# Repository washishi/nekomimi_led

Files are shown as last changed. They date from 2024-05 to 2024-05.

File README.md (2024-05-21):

# Nekomimi LED  
M5StackのGO BOTTOM等に直接取り付けれるオリジナルのネコミミ型LED基板です  
NeoPixel(WS2812)互換のRGB LEDが左右に9個ずつ合計18個付いており独立して色や明るさ等を制御することができます  
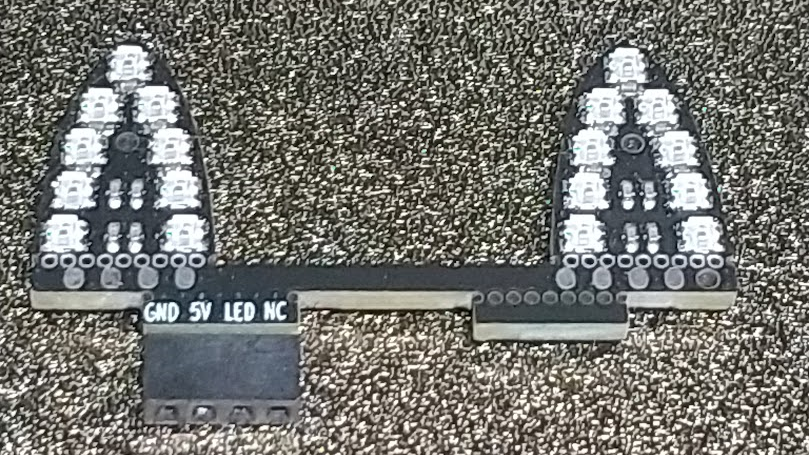
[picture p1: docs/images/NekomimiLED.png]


※完成品 や 組立キット、オプション外装等を[Booth](https://washishi.booth.pm/)で頒布もしています
# 回路図、作り方
  回路図、作り方等の詳細については[こちら](schematics/docs/README.md)へ  
  オプション外装の利用方法については[こちら](case/README.md)へ
  <br>

# 使い方
主に下記に直接取り付けることができます  
- <a href="https://docs.m5stack.com/ja/base/m5go_bottom" target="_blank" rel="noopener noreferrer">M5GO BOTTOM</a> BASIC用 (M5GO,FIREは標準添付)   
- <a href="https://docs.m5stack.com/ja/base/m5go_bottom2" target="_blank" rel="noopener noreferrer">M5GO BOTTOM2</a> CORE2用 (CORE2 for AWS は標準添付)
- <a href="https://docs.m5stack.com/ja/module/M5GO3%20Bottom" target="_blank" rel="noopener noreferrer">M5GO3 BOTTOM</a> CoreS3用 (DINベースにそのままつけた場合はコネクタ位置が異なるため左寄りになります)
  
取り付け例  
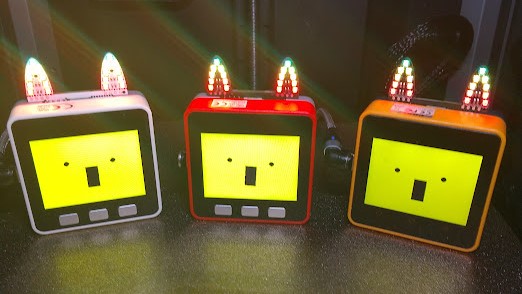
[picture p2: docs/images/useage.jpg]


なおM5Stick系やM5Atom系、M5DialやM5NanoC6などもGROVEポートがあれば基本的に利用可能です  
物理的に干渉する場合はGROVEケーブルとGROVEコネクタを使えば[延長して取り付ける](docs/images/cable_connect.png)こともできます   
<br>  

また[オプション外装](case)を利用してはんだ付けを含む工作を行う場合は下記に取り付け可能となります
  - 直接取り付けできる前記のGO BOTTOM系全て
  - <a href="https://docs.m5stack.com/ja/base/DIN%20BASE" target="_blank" rel="noopener noreferrer">DIN BASE</a> (CoreS3に標準添付)  
  - ししかわさん版(アールティVer. α版,β版)ｽﾀｯｸﾁｬﾝ (V0.2.1基板にPH-4Pコネクタ実装済の物)  

<br>
オプション外装を利用した取り付け例  

&emsp;左から DIN BASE基板ｽﾀｯｸﾁｬﾝ、ししかわさん版ｽﾀｯｸﾁｬﾝ、GO BOTTOM2基板ｽﾀｯｸﾁｬﾝ  

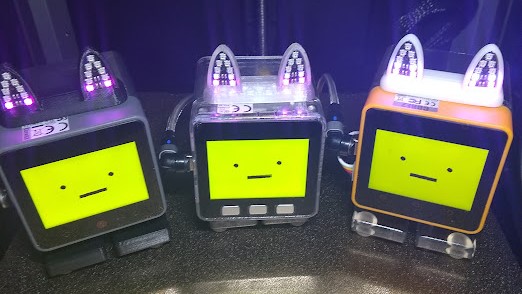
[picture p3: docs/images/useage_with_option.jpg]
  

# 使用するGPIO
GO_BOTTOM系やDIN BASEへの接続 または ｽﾀｯｸﾁｬﾝ基板 V0.2.1 の場合は  
PortBのOUTPUT(O)端子を利用してGPIO番号は下記となります  
|Core|利用するGPIO|  
|:--|:-:|
|BASIC/GRAY/M5GO/FIRE|26|  
|CORE2/CORE2 for AWS|26|  
|CoreS3|9|  

# ソフトウエアでの利用について
Arduino IDE や VSCode + PlatformIO で利用する場合は
[FastLED](https://github.com/FastLED/FastLED)や[Adafruit NeoPixel](https://github.com/adafruit/Adafruit_NeoPixel)等のライブラリで利用できます  
UIFlowで利用する場合はUnit RGB で LEDの数を 18 として利用できます  
その他に関しては NeoPixel を操作できるライブラリ等があれば利用できると思います

# サンプルプログラム
サンプルプログラムとして [m5stack-avatar-mic-nekomimi_led](https://github.com/washishi/m5stack-avatar-mic-nekomimi_led) を用意しました  
音に合わせてAvatarが口パクしたり、傾いたりすると共にNekomimi LEDが音量に応じて光ります
※Takao Akaki (mongonta0716) さんの [m5stack-avatar-mic](https://github.com/mongonta0716/m5stack-avatar-mic) を改変したものです

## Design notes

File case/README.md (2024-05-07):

# オプション外装の利用方法
## 必要なもの
 - はんだごて、ハンダ 等
 - ピンセット
 - ニッパー
 - やすり
 - オプション外装 ([case](../case)配下にある3Dデータを自分で印刷 または JLCPCBなどの製造会社へ委託等してください  
   なおstlとstep形式のデータがありますが内容は同じものです)
 - 0.16mmぐらいの ポリウレタン(UEW)線 30cm程（参考：[秋月電子 111531](https://akizukidenshi.com/catalog/g/g111531/)）
 - 瞬間接着剤や両面テープ等の固定するもの

作成方法  
 - [基板の加工](../schematics#基板の加工について)をします  
 - ポリウレタン(UEW)線 を 3cmぐらいに切ったものを7本作り両端をはんだメッキします
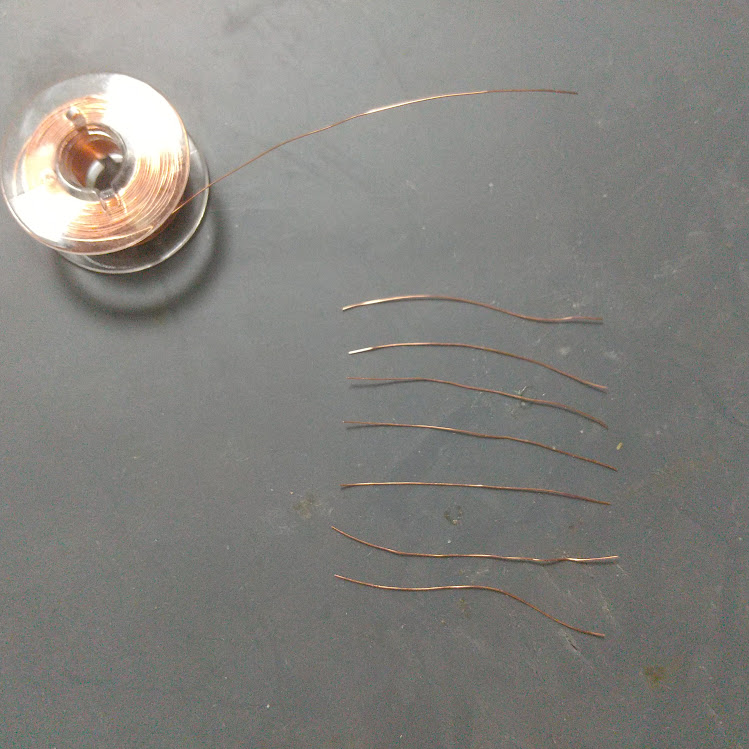
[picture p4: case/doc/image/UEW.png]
 

 - 切り取った基板にはんだ付けします  
 　(写真で下側4本、上側は一番上を除いた3本)  
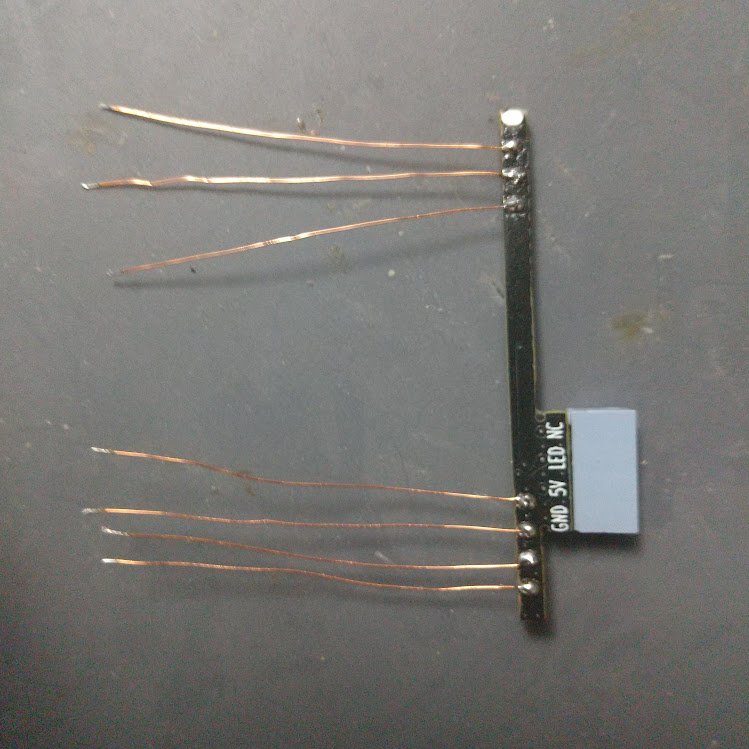
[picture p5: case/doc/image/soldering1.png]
    

 - 外装の穴にポリウレタン(UEW)線を通します この段階で線の順番がわかるようにしておいてください  
 (わからなくなってしまった場合はテスター等で導通を確認してください)

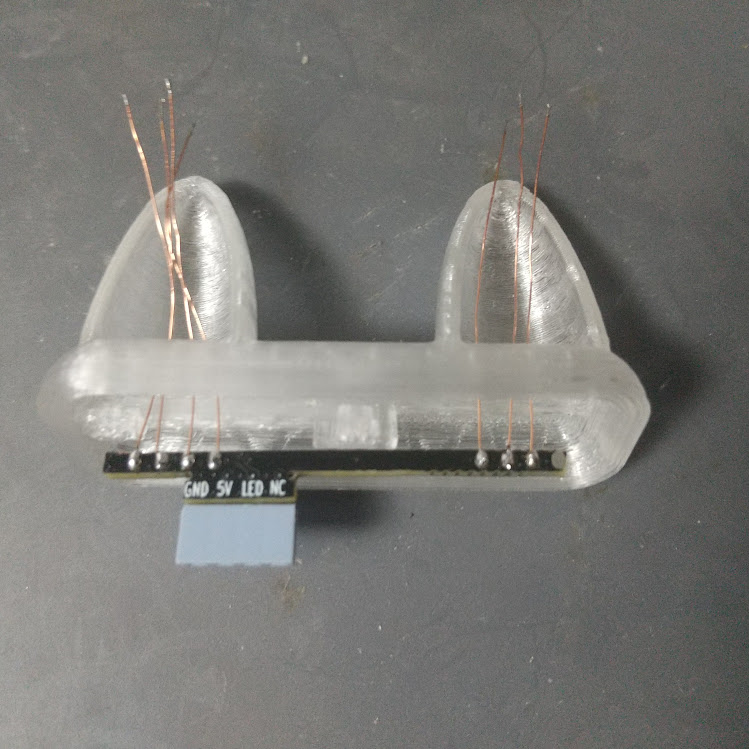
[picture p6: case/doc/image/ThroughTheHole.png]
    
  
 - ピンソケットのついた基板を写真の位置に奥まで押し込みます  
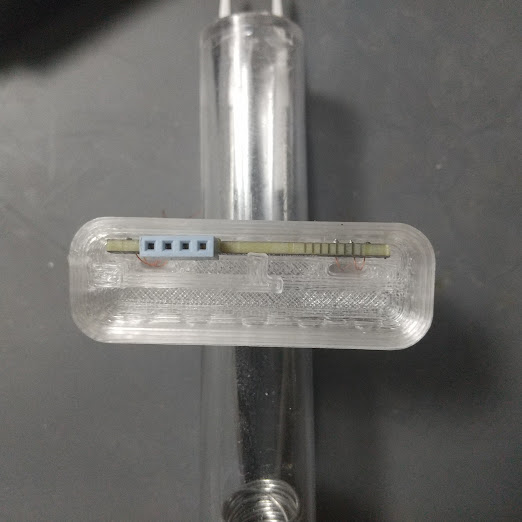
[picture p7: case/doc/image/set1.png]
  

 - スライドして出っ張りの下に入れる  
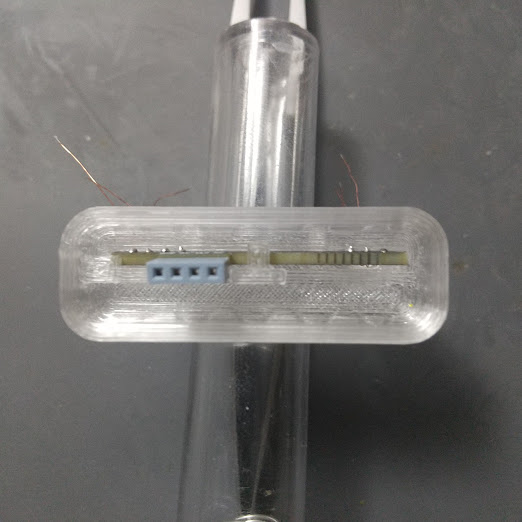
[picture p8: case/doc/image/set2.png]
  

 - ししかわさん(RT α,β版)用の場合は右側  
DIN BASE用の場合は左側に基板を寄せます  
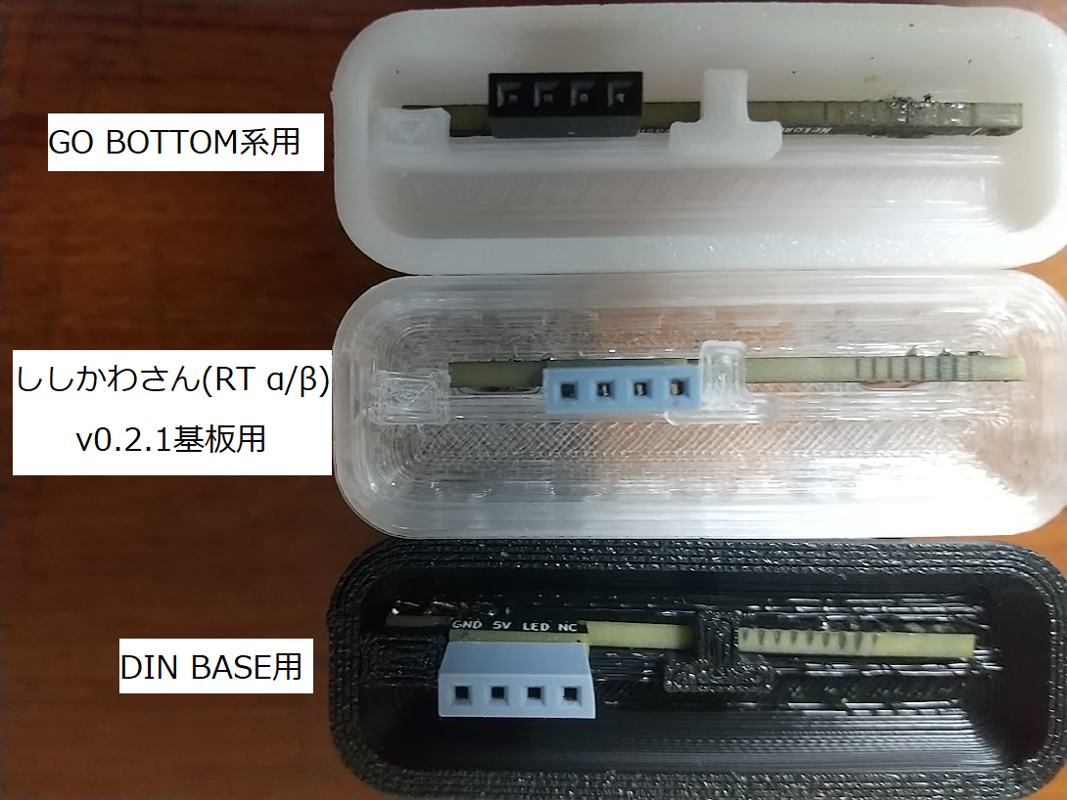
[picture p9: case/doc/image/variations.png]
 

 - ネコミミ部分のはんだ付けを行います  
 (写真では上部側のOUT端子は利用しません)  
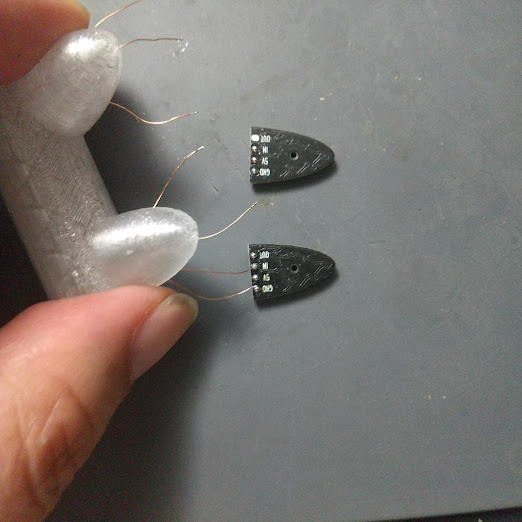
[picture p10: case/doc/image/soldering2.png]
 
 
 - ポリウレタン(UEW)線を曲げて外装にネコミミ部分を押し込みます  
 またそのままでは外れやすいので瞬間接着剤や両面テープ等で固定してください
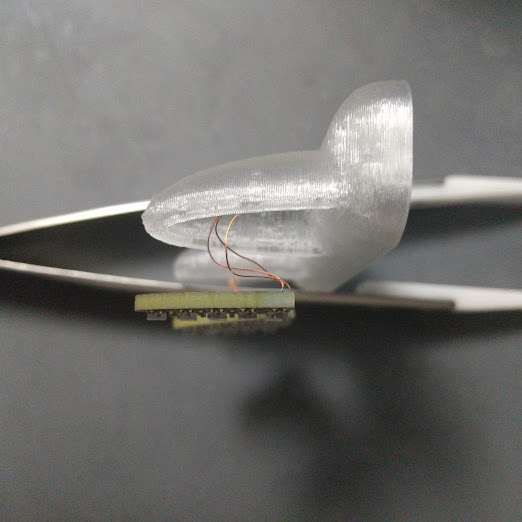
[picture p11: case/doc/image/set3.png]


 - 完成  
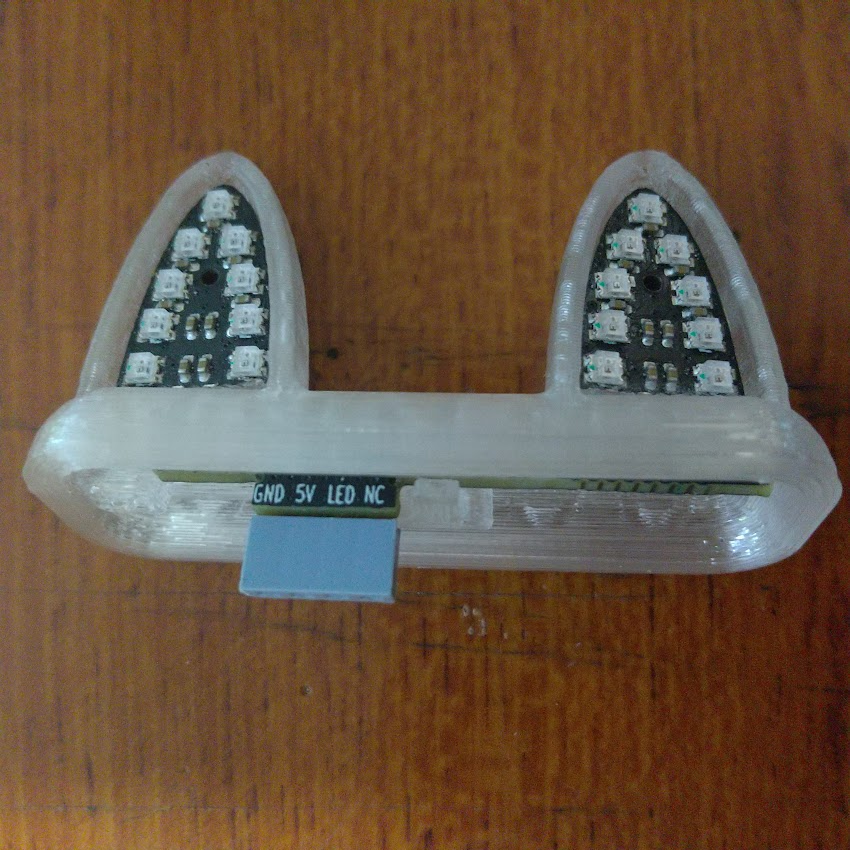
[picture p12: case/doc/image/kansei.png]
 

 - ｽﾀｯｸﾁｬﾝに取り付けた場合  
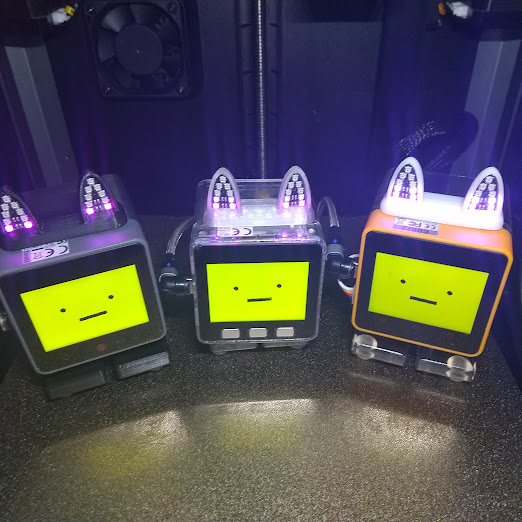
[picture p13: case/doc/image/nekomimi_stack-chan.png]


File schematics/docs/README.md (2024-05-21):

# 回路図  
回路的にはマイコン内蔵RGB LEDを18個繋げただけの回路です  
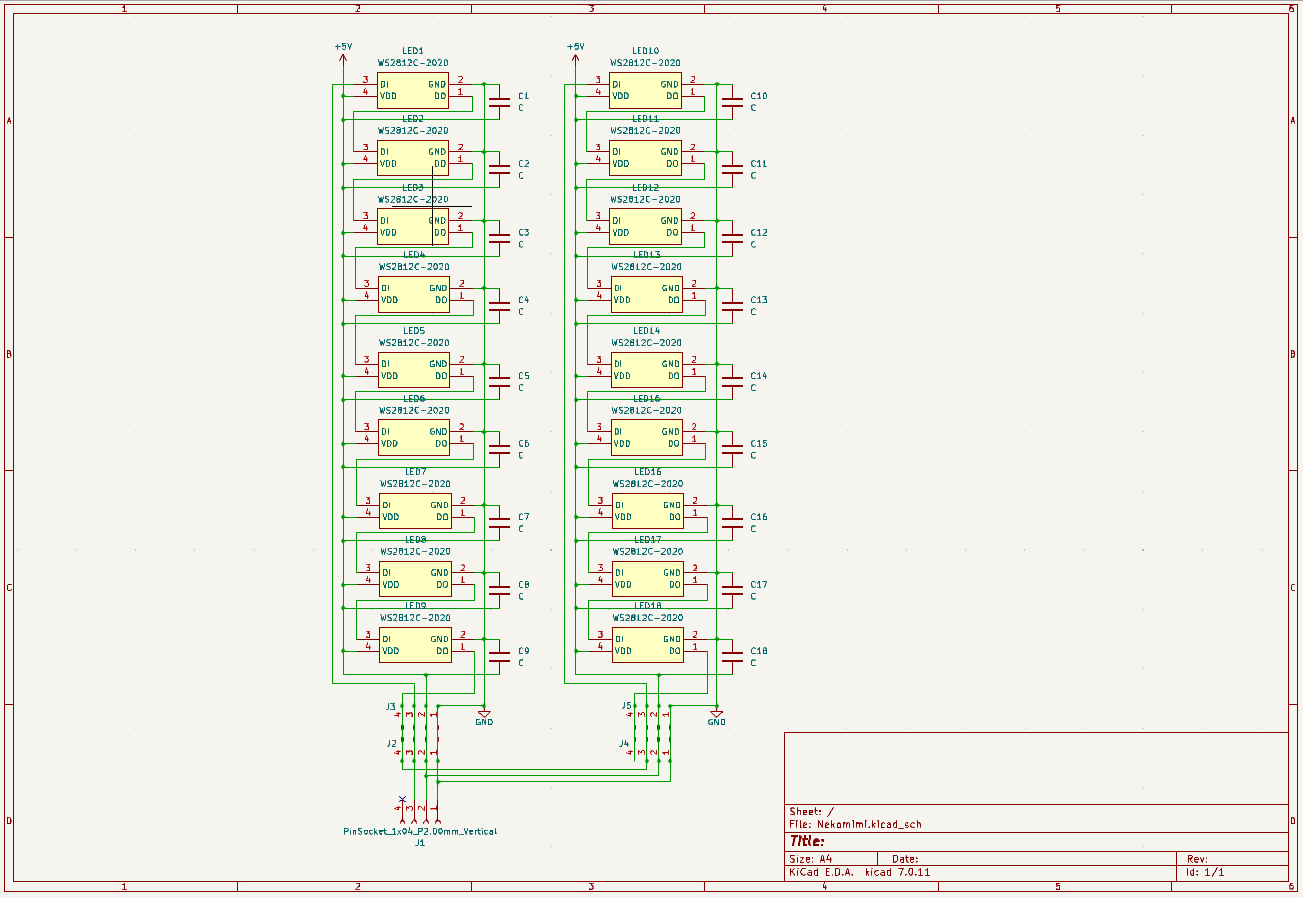
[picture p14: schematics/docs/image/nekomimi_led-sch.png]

<br>  
<br>  

# 部品表
|品名|部品番号|型番等|数量|入手先(参考)|備考|
|:--|:--|:--|--:|:--|:--|
|基板|-|Nekomimi_LED 基板|1|JLCPCBへ発注|基板の発注について参照|
|コンデンサ|C1～C18|チップ1005サイズ 0.1uF|18|秋月電子 ([113377](https://akizukidenshi.com/catalog/g/g113377/))<br>　※1パック25個||
|LED|LED1～LED18|マイコン内蔵RGBLED<br>WS2812C-2020 または互換品|18|秋月電子 ([115068](https://akizukidenshi.com/catalog/g/g115068/))<br>　※1パック 10個||
|ピンソケット|J1|2mmピッチ 4ピン|1|秋月電子 ([103870](https://akizukidenshi.com/catalog/g/g103870/))<br>　※5ピン目のところで切って利用||
<br>

# 基板実装図  
表面：チップコンデンサ、LEDをはんだ付けします  
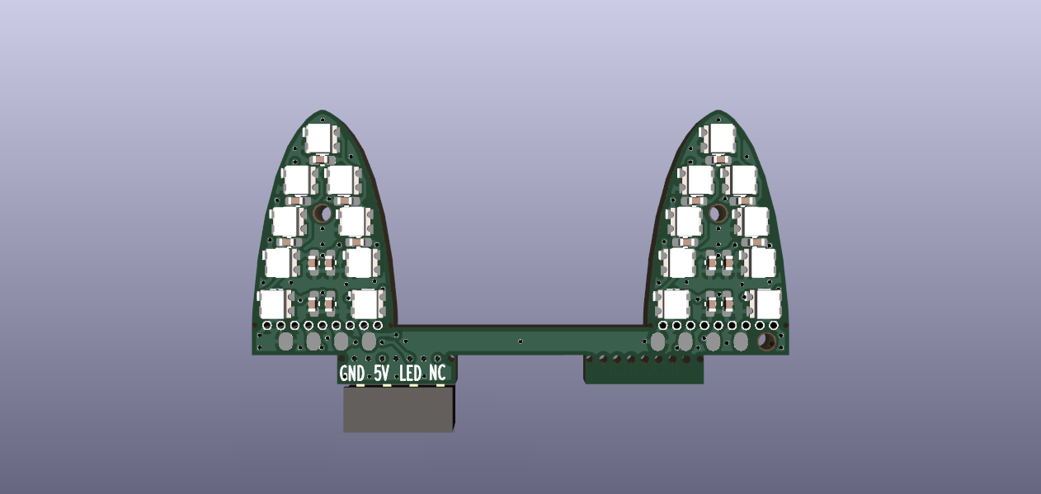
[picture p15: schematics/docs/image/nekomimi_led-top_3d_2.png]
  
裏面：GROVEコネクタへ差し込むためのピンソケットをはんだ付けします  
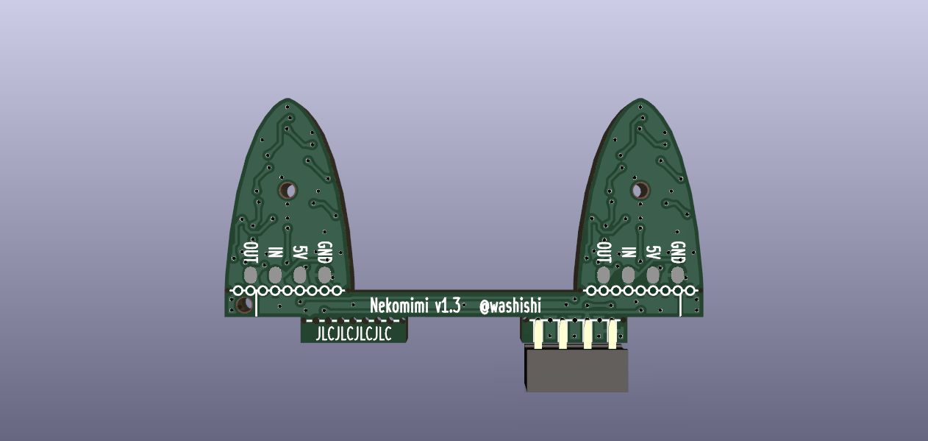
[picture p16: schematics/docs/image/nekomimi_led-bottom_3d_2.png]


# 基板パターン図  
 [schematics](../../schematics/)ディレクトリに[KiCad](https://www.kicad.org/)で作成したデータがあります  
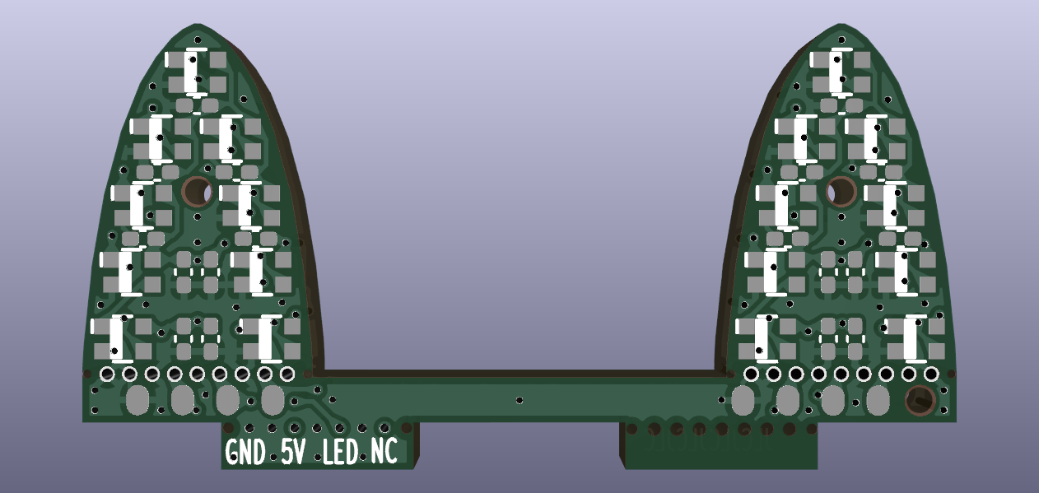
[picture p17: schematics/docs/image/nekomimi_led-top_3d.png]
  
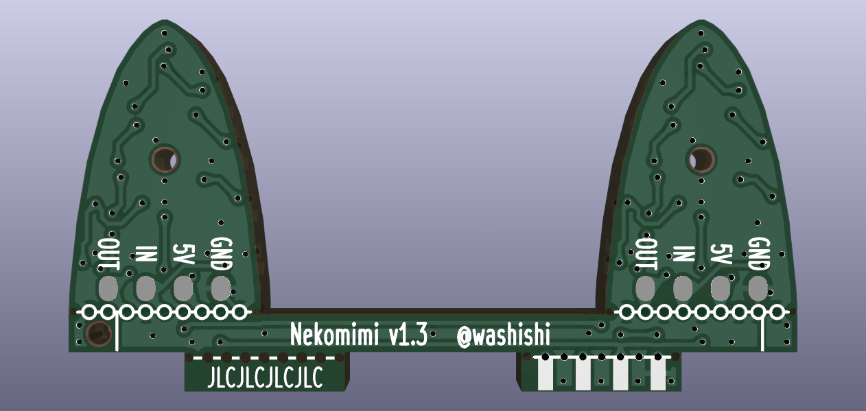
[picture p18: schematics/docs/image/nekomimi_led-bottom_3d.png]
  

# 基板の発注について  
[JLCPCB](https://jlcpcb.jp/)用に作った発注用データがあるのでこちらを利用して発注してください
- ガーバーファイル(基板データ) [Nekomimi.zip](../production/Nekomimi.zip) 
- PCBA用 BOMファイル(部品情報) [bom.csv](../production/bom.csv)
- PCBA用 CPLファイル(位置情報)  [positions.csv](../production/positions.csv)  

## 発注時の指定について
- ガーバーファイルの追加：事前にダウンロードしたガーバファイル [Nekomimi.zip](../production/Nekomimi.zip)をクリックして選択 (展開せずzipのまま選択してください)
- PCB数量：作成する基板の枚数 最低5枚から
- PCBカラー： お好みの色を選んでください
- 発注番号の削除：「場所の指定」を選択 (JLCJLCJLCJLCのシルク位置に入ります) 
- 配送方法の選択： 特に急がない場合は一番安いOCS NEPでいいと思います

&emsp;その他はデフォルトで問題ありません  

&emsp;PCB組み立て(PCBA)も頼む場合は下記を参考にしてください  

- 組立サイド：「トップ面」
- ツーリングホール ：「お客様に追加される」
- BOMファイルの追加 ：事前にダウンロードしたBOMファイル [bom.csv](../production/bom.csv)をクリックして選択
- CPLファイルの追加 ：事前にダウンロードしたCPLファイル [positions.csv](../production/positions.csv)をクリックして選択
- 部品表 (実装部品の選択)：コンデンサ(C1～18)とLED(LED1～18)が選択可能です  
  しかしLEDが熱に弱い等で実装難易度の難しい部品という扱いになっている為選択すると標準PCBAへの切り替えが必要となります  
  またエッジレール付加も必要となりかなり高額になってしまいます  
  そのため個人的には実装も頼む場合はコンデンサだけにしてLEDは自分ではんだ付けした方がいいと思います
- 配送方法の選択：特に急がない場合は一番安いOCS Expressでいいと思います
<br>
<br>

参考として5枚作成して一番安い配送で東京に配送した場合のおおよその費用です  
|区分|基板費用|実装・部品代|発送方法|送料|合計|
|:--|--:|--:|:--|--:|--:|
|基板製造のみ|$2.00|-|OCS NEP|$0.96|$2.96|
|コンデンサのみ実装|$2.00|$9.89|OCS Express|$2.01|$13.90|
|コンデンサとLEDを実装|$2.00|$42.11|OCS Express|$9.13|$53.24|
<br>

# 基板の組み立てについて
組み立ては以下のような工具が必要です
 - はんだごて(場所が狭いのでこて先は細いI型やJ形が使いやすいかも)、ハンダ
 - フラックス および フラックスクリーナー等
 - ピンセット
 - ニッパー
 - やすり(ダイヤモンドやすりがいいです、100均で売っているもので十分です)

　なおチップ部品のはんだ付けは一応手はんだでも可能ですが
ヒートテーブル等を使ったリフローが行えると比較的容易です  
<br>

## 制作方法
 - 基板を[JLCPCB](https://jlcpcb.jp/)等の製造業者に発注します
 - チップコンデンサ、LED の未実装のチップ部品を実装します
 - ピンソケットが4ピンの物でない場合はニッパーで5ピン目のところで切断してやすりで整えて4ピンのピンソケットを作ります
 - ピンソケットをはんだ付けします

LEDの実装向きは下記の様になります  
  ※下記は互換LEDの写真です、LEDによっては印やラインは一部無い物もあります  
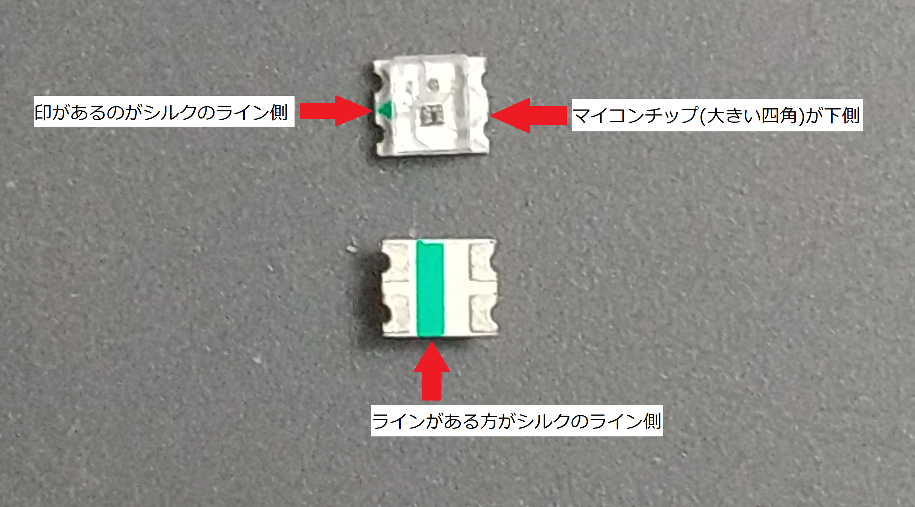
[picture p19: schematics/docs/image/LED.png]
  

# 基板の加工について  
　 そのままでも使えますが、PortCを使いたい場合や[オプション外装を利用](../../case/README.md#オプション外装の利用方法)したい場合は基板の加工が必要です  

裏面図  
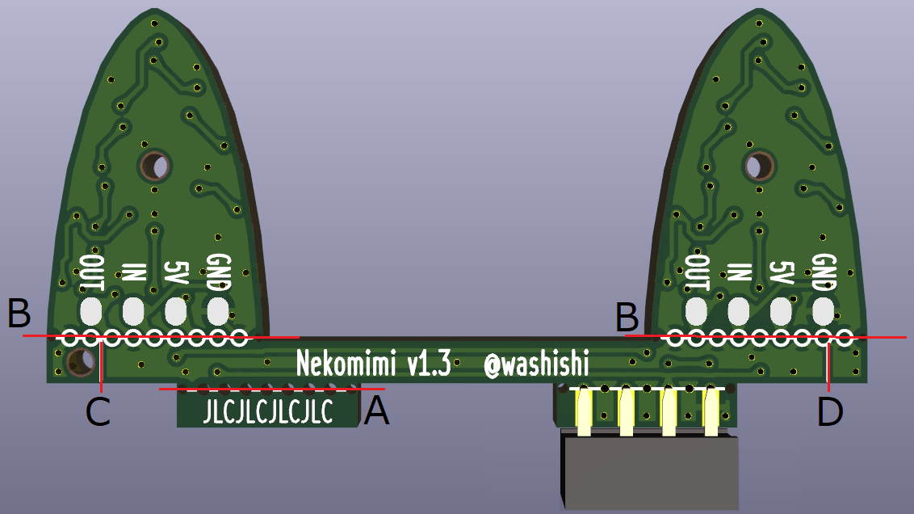
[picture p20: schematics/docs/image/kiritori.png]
  
- A：PortCを利用する場合やオプション外装を利用してGO BOTTOM系以外に使用する場合に切ります
- B：オプション外装を利用する場合に切ります
- C：オプション外装を使ってししかわさん版(アールティVer. α版,β版)ｽﾀｯｸﾁｬﾝ  
　 (V0.2.1基板にPH-4Pコネクタ実装済の物)に取り付ける場合にBを切った後に切ります
- D：オプション外装を使ってDIN BASEに取り付ける場合にBを切った後に切ります

## 切り取り方法 (一例)
必要なもの  アートナイフまたはカッターナイフ等、ニッパー、やすり
 - 切り取りたい場所をアートナイフやカッターナイフである程度切込みが付くまで切ります(可能であれば両面から切ってください)
 - 切込みを付けた部分をニッパーで挟む(切るのではなく挟むだけ、ラジオペンチ等で挟むと基板のパターンを傷つけてしまう場合があるので注意)
 - 切り取りたい部分を上下に押して割って切り取ります
 - 切り取った後のバリはやすりで整えます (切断面のスルーホールのメッキがなくなるまで削って大丈夫です、また粉塵が出るので各自対策等願います)

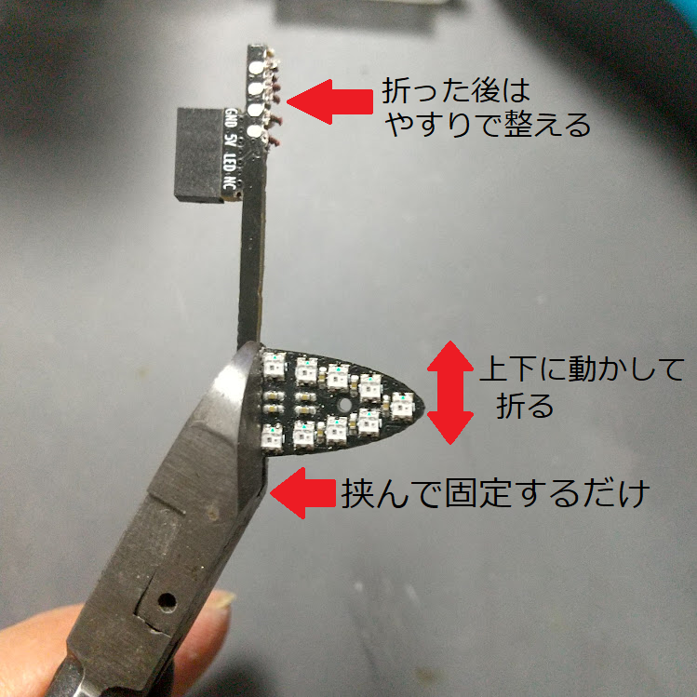
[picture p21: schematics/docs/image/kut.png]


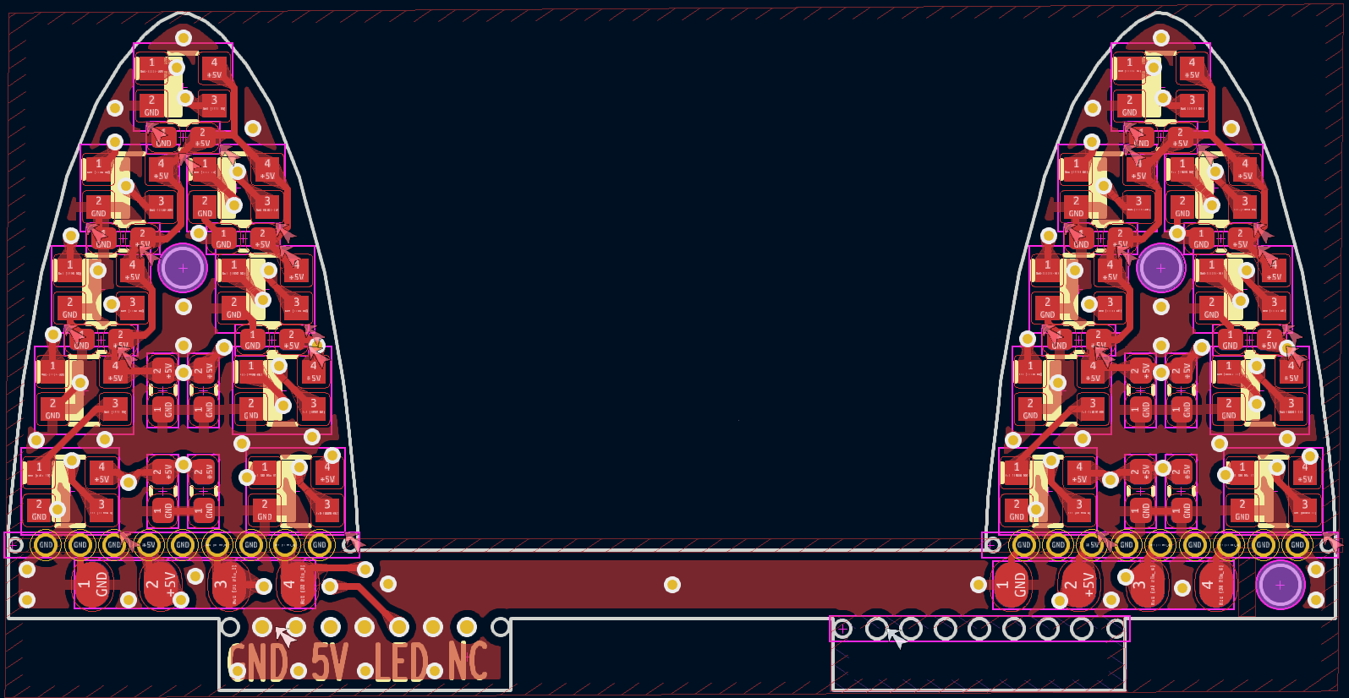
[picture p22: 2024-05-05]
schematics/docs/image/nekomimi_led-top.png

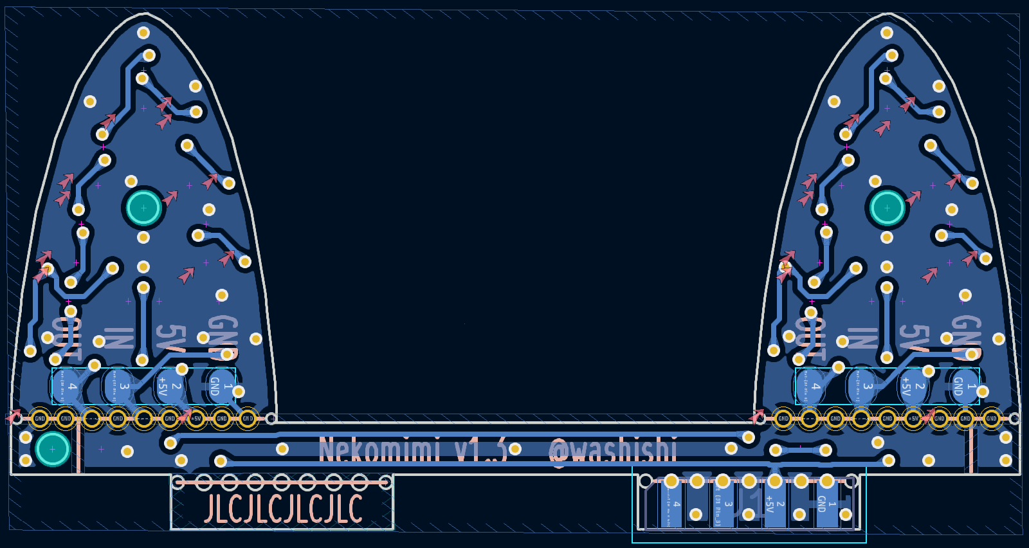
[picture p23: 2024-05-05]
schematics/docs/image/nekomimi_led-bottom..png

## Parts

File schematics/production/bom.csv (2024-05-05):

Designator | Footprint | Quantity | Value | LCSC Part #
C1, C10, C11, C12, C13, C14, C15, C16, C17, C18, C2, C3, C4, C5, C6, C7, C8, C9 | 0402 | 18 | C | C1525
LED1, LED10, LED11, LED12, LED13, LED14, LED15, LED16, LED17, LED18, LED2, LED3, LED4, LED5, LED6, LED7, LED8, LED9 | WS2812C2020 | 18 | WS2812C-2020 | C2976072

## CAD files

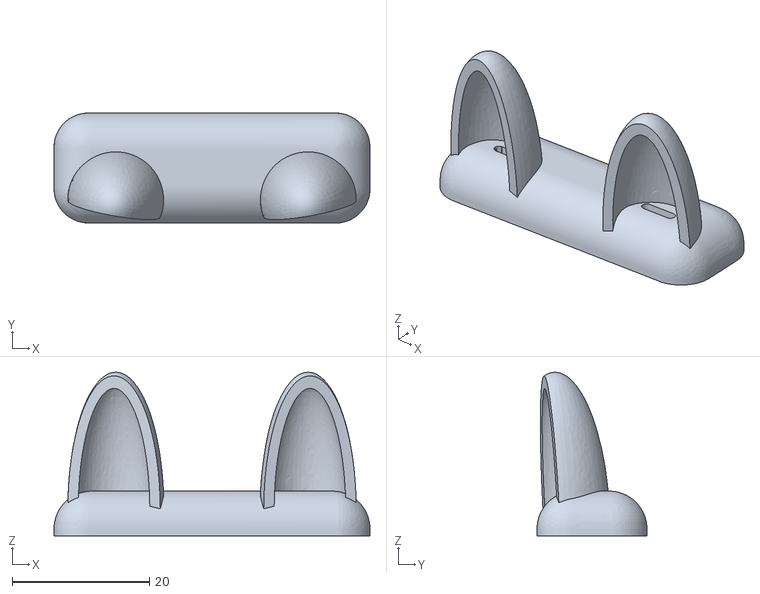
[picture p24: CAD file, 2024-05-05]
case/hat_cat_ear_v2.0_mod.stl
46.0 x 16.0 x 23.8

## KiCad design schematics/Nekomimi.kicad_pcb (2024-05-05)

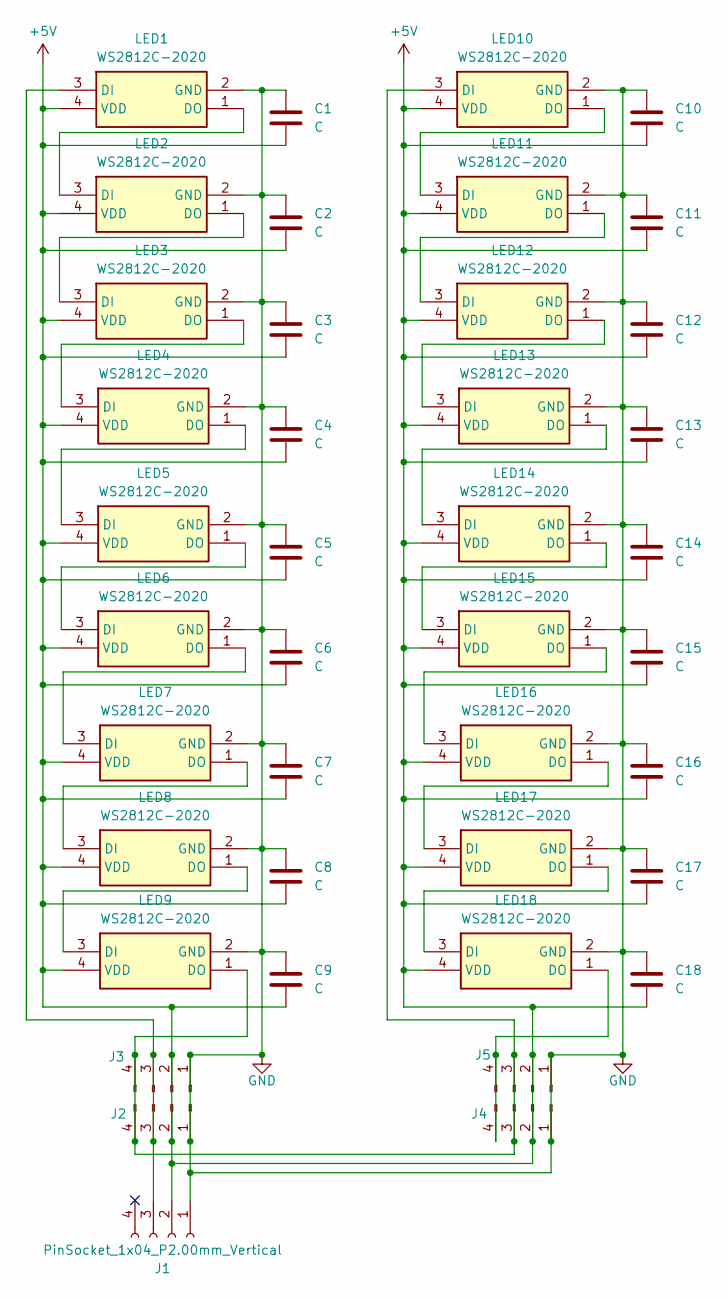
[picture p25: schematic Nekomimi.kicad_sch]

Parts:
C1, C2, C3, C4, C5, C6, C7, C8, C9, C10, C11, C12, C13, C14, C15, C16, C17, C18: C; C_0402_1005Metric_Pad0.74x0.62mm_HandSolder; LCSC C1525
J1: PinSocket_1x04_P2.00mm_Vertical
J2, J3, J4, J5: Conn_01x04_Pin; Pad_1x04_P2.00mm
LED1, LED2, LED3, LED4, LED5, LED6, LED7, LED8, LED9, LED10, LED11, LED12, LED13, LED14, LED15, LED16, LED17, LED18: WS2812C-2020; WS2812C2020; Manufacturer_Part_Number WS2812C-2020; LCSC C2976072

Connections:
+5V: C1.2, C2.2, C3.2, C4.2, C5.2, C6.2, C7.2, C8.2, C9.2, C10.2, C11.2, C12.2, C13.2, C14.2, C15.2, C16.2, C17.2, C18.2, J1.2, J2.2, J3.2, J4.2, J5.2, LED1.4 (VDD), LED2.4 (VDD), LED3.4 (VDD), LED4.4 (VDD), LED5.4 (VDD), LED6.4 (VDD), LED7.4 (VDD), LED8.4 (VDD), LED9.4 (VDD), LED10.4 (VDD), LED11.4 (VDD), LED12.4 (VDD), LED13.4 (VDD), LED14.4 (VDD), LED15.4 (VDD), LED16.4 (VDD), LED17.4 (VDD), LED18.4 (VDD)
GND: C1.1, C2.1, C3.1, C4.1, C5.1, C6.1, C7.1, C8.1, C9.1, C10.1, C11.1, C12.1, C13.1, C14.1, C15.1, C16.1, C17.1, C18.1, J1.1, J2.1, J3.1, J4.1, J5.1, LED1.2 (GND), LED2.2 (GND), LED3.2 (GND), LED4.2 (GND), LED5.2 (GND), LED6.2 (GND), LED7.2 (GND), LED8.2 (GND), LED9.2 (GND), LED10.2 (GND), LED11.2 (GND), LED12.2 (GND), LED13.2 (GND), LED14.2 (GND), LED15.2 (GND), LED16.2 (GND), LED17.2 (GND), LED18.2 (GND)
unnamed: J1.3, J2.3, J3.3, LED1.3 (DI)
unnamed: J2.4, J3.4, J4.3, J5.3, LED9.1 (DO), LED10.3 (DI)
unnamed: J4.4, J5.4, LED18.1 (DO)
unnamed: LED1.1 (DO), LED2.3 (DI)
unnamed: LED2.1 (DO), LED3.3 (DI)
unnamed: LED3.1 (DO), LED4.3 (DI)
unnamed: LED4.1 (DO), LED5.3 (DI)
unnamed: LED5.1 (DO), LED6.3 (DI)
unnamed: LED6.1 (DO), LED7.3 (DI)
unnamed: LED7.1 (DO), LED8.3 (DI)
unnamed: LED8.1 (DO), LED9.3 (DI)
unnamed: LED10.1 (DO), LED11.3 (DI)
unnamed: LED11.1 (DO), LED12.3 (DI)
unnamed: LED12.1 (DO), LED13.3 (DI)
unnamed: LED13.1 (DO), LED14.3 (DI)
unnamed: LED14.1 (DO), LED15.3 (DI)
unnamed: LED15.1 (DO), LED16.3 (DI)
unnamed: LED16.1 (DO), LED17.3 (DI)
unnamed: LED17.1 (DO), LED18.3 (DI)

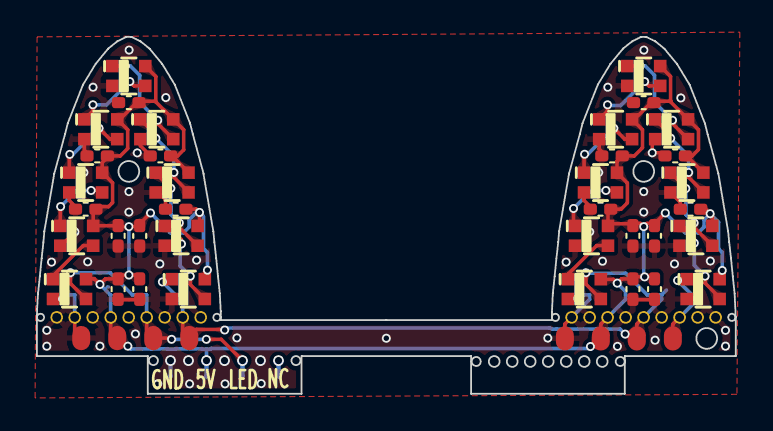
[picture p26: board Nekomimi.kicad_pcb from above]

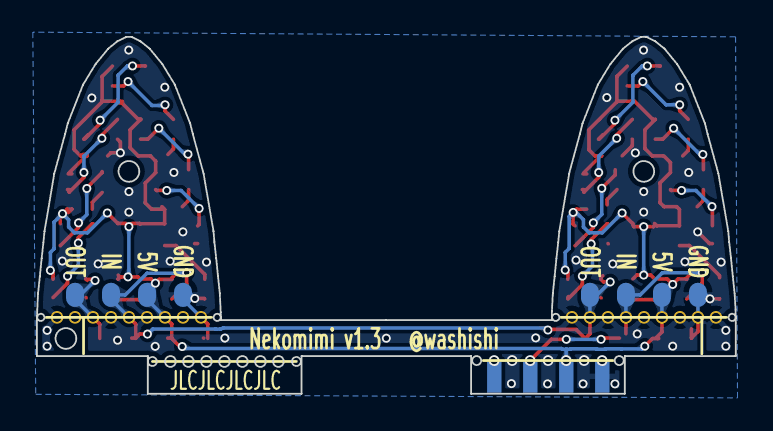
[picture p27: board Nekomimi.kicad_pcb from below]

Board: 2 copper layers, 38.8 x 19.8 mm, 47 parts (3 on the bottom side), 21 nets.

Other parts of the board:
hole1, hole2: Hole_1x11 P1.00mm; Hole_1x11_P1.00mm
hole3: Hole_1x9 P1.00mm; Hole_1x9_P1.00mm
tooling hole1, tooling hole2, tooling hole3: Tooling Hole 1.152mm; PCBA_Tooling_Hole
